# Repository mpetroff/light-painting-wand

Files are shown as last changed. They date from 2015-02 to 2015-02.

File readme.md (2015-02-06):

# Light Painting Wand

This repository contains hardware designs, firmware, and software for creating
a light painting wand. For more information see
[this blog post](http://mpetroff.net/2015/02/light-painting-wand/).

## License

All code is licensed under the
[MIT license](http://opensource.org/licenses/MIT).

The hardware design files are licensed under the
[CC BY 4.0 license](http://creativecommons.org/licenses/by/4.0/).

## Credits

[Matthew Petroff](http://mpetroff.net/)

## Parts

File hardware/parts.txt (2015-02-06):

Part                Qty     Manufacturer        Manufacturer #          Mouser #

Micro SD socket     1       Hirose Electric     DM3BT-DSF-PEJS          798-DM3BT-DSF-PEJS
16 MHz crystal      1       ABRACON             ABLS-16.000MHZ-B4-T     815-ABLS-16.0M-T
Voltage regulator   1       Micrel              MIC5504-3.3YM5 TR       998-MIC5504-3.3YM5TR
Level translator    1       Texas Instruments   SN74LVC1T45QDCKRQ1      595-74LVC1T45QDCKRQ1
1uF capacitor       2       Murata              GRM188R61E105KA12D      81-GRM188R61E105KA12
27pF capacitor      2       Vishay              VJ0603A270JXACW1BC      77-VJ0603A270JXACBC
2.2uF capacitor     1       Taiyo Yuden         JMK107BJ225KAHT         963-JMK107BJ225KAHT
0.1uF capacitor     6       Vishay              VJ0603Y104JXQCW1BC      77-VJ0603Y104JXQCBC
Microcontroller     1       Freescale Semi.     MK20DX256VLH7           841-MK20DX256VLH7
Switch              4       C&K Components      D6C30 F1 LFS            611-D6C30F1LFS
Terminal block      1       Phoenix Contact     1935174                 651-1935174
68 ohm resistor     1       Vishay              CRCW060368R0FKEA        71-CRCW0603-68-E3

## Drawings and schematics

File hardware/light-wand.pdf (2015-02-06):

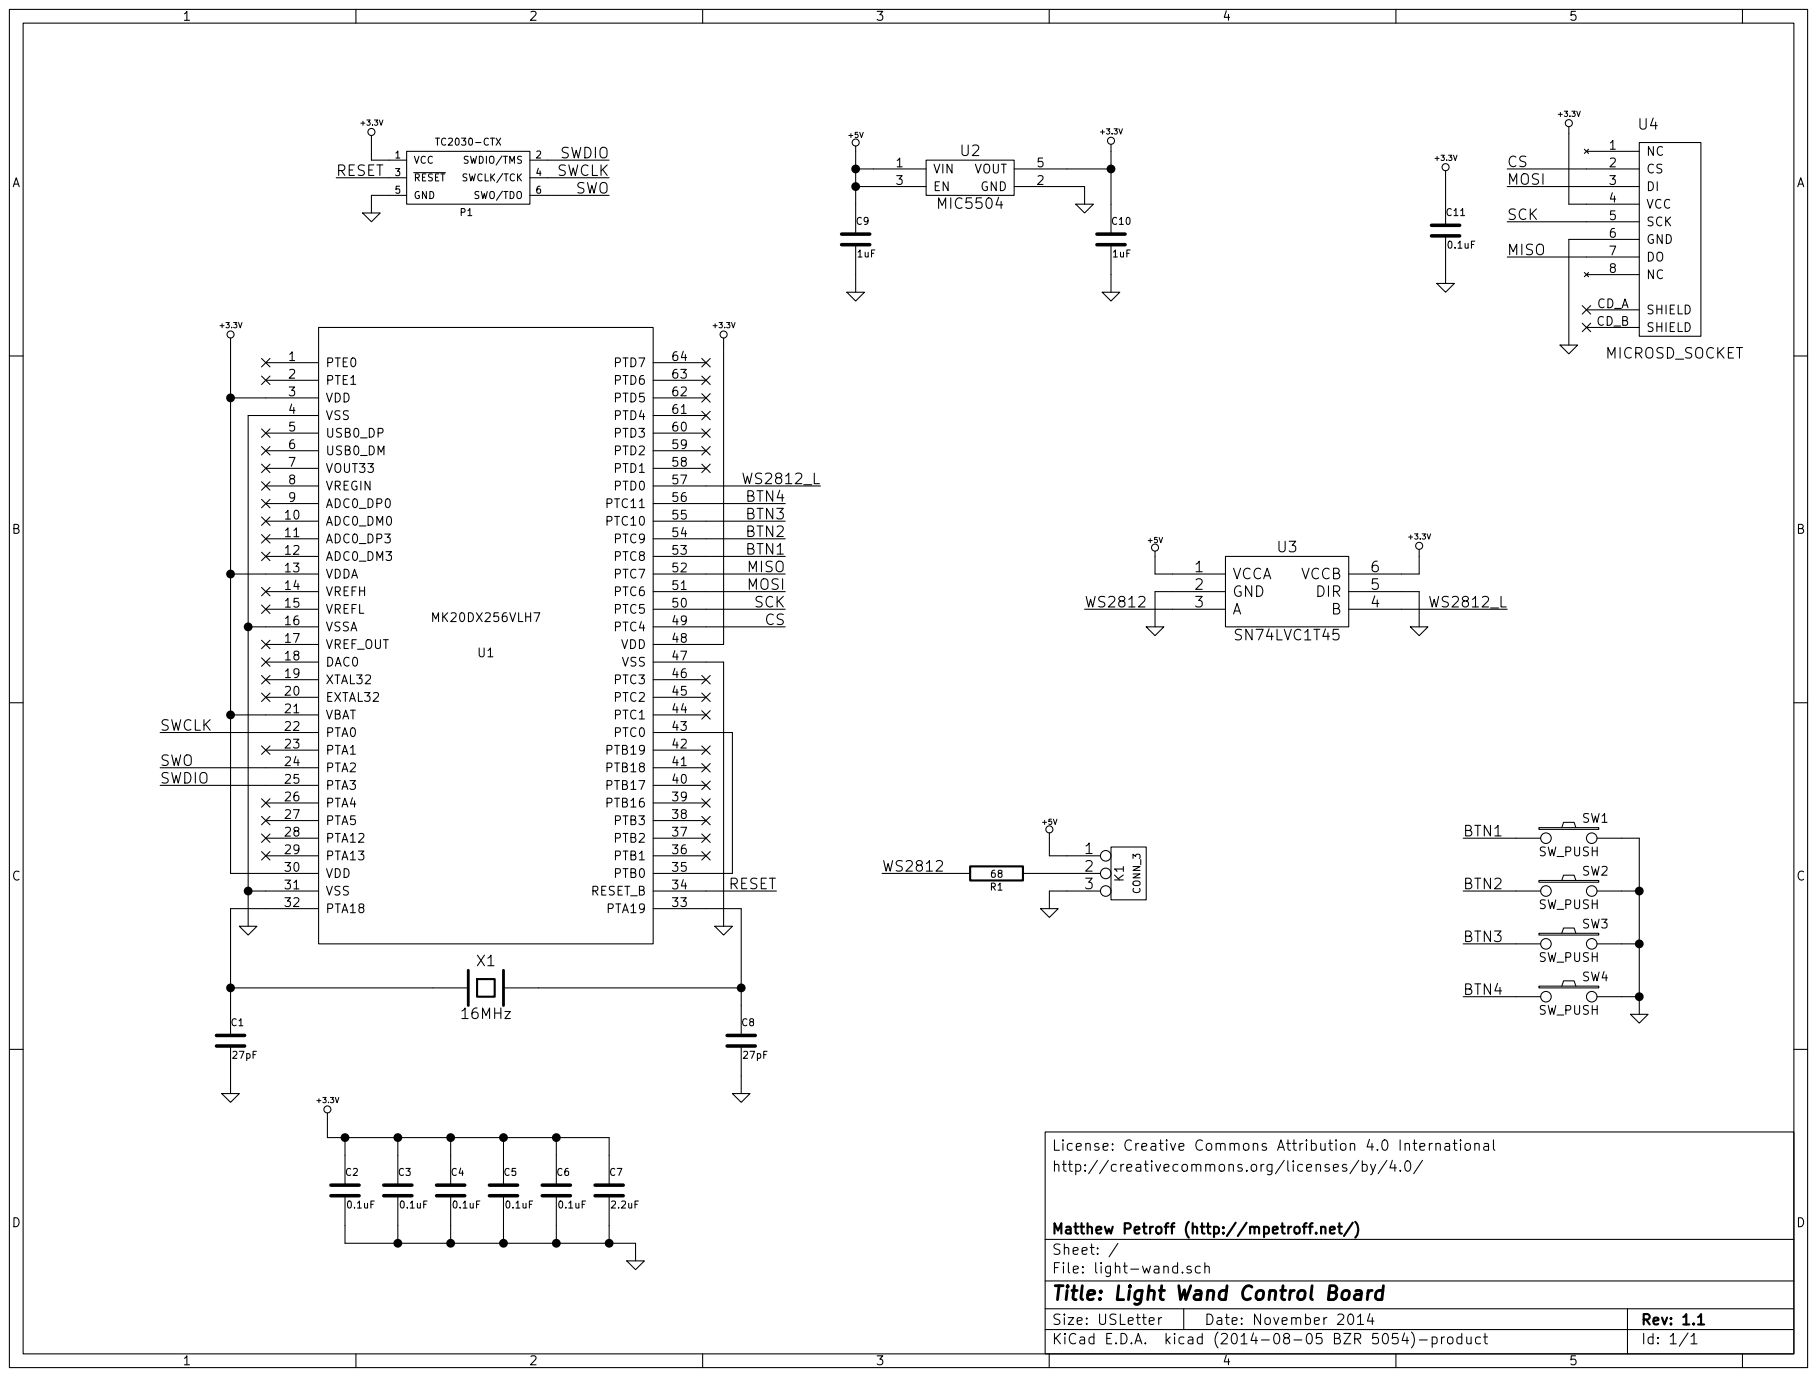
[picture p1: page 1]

http://creativecommons.org/licenses/by/4.0/ License: Creative Commons Attribution 4.0 International 1

File: light-wand.sch Sheet: / Matthew Petroff (http://mpetroff.net/)

Id: 1/1 Title: Light Wand Control Board

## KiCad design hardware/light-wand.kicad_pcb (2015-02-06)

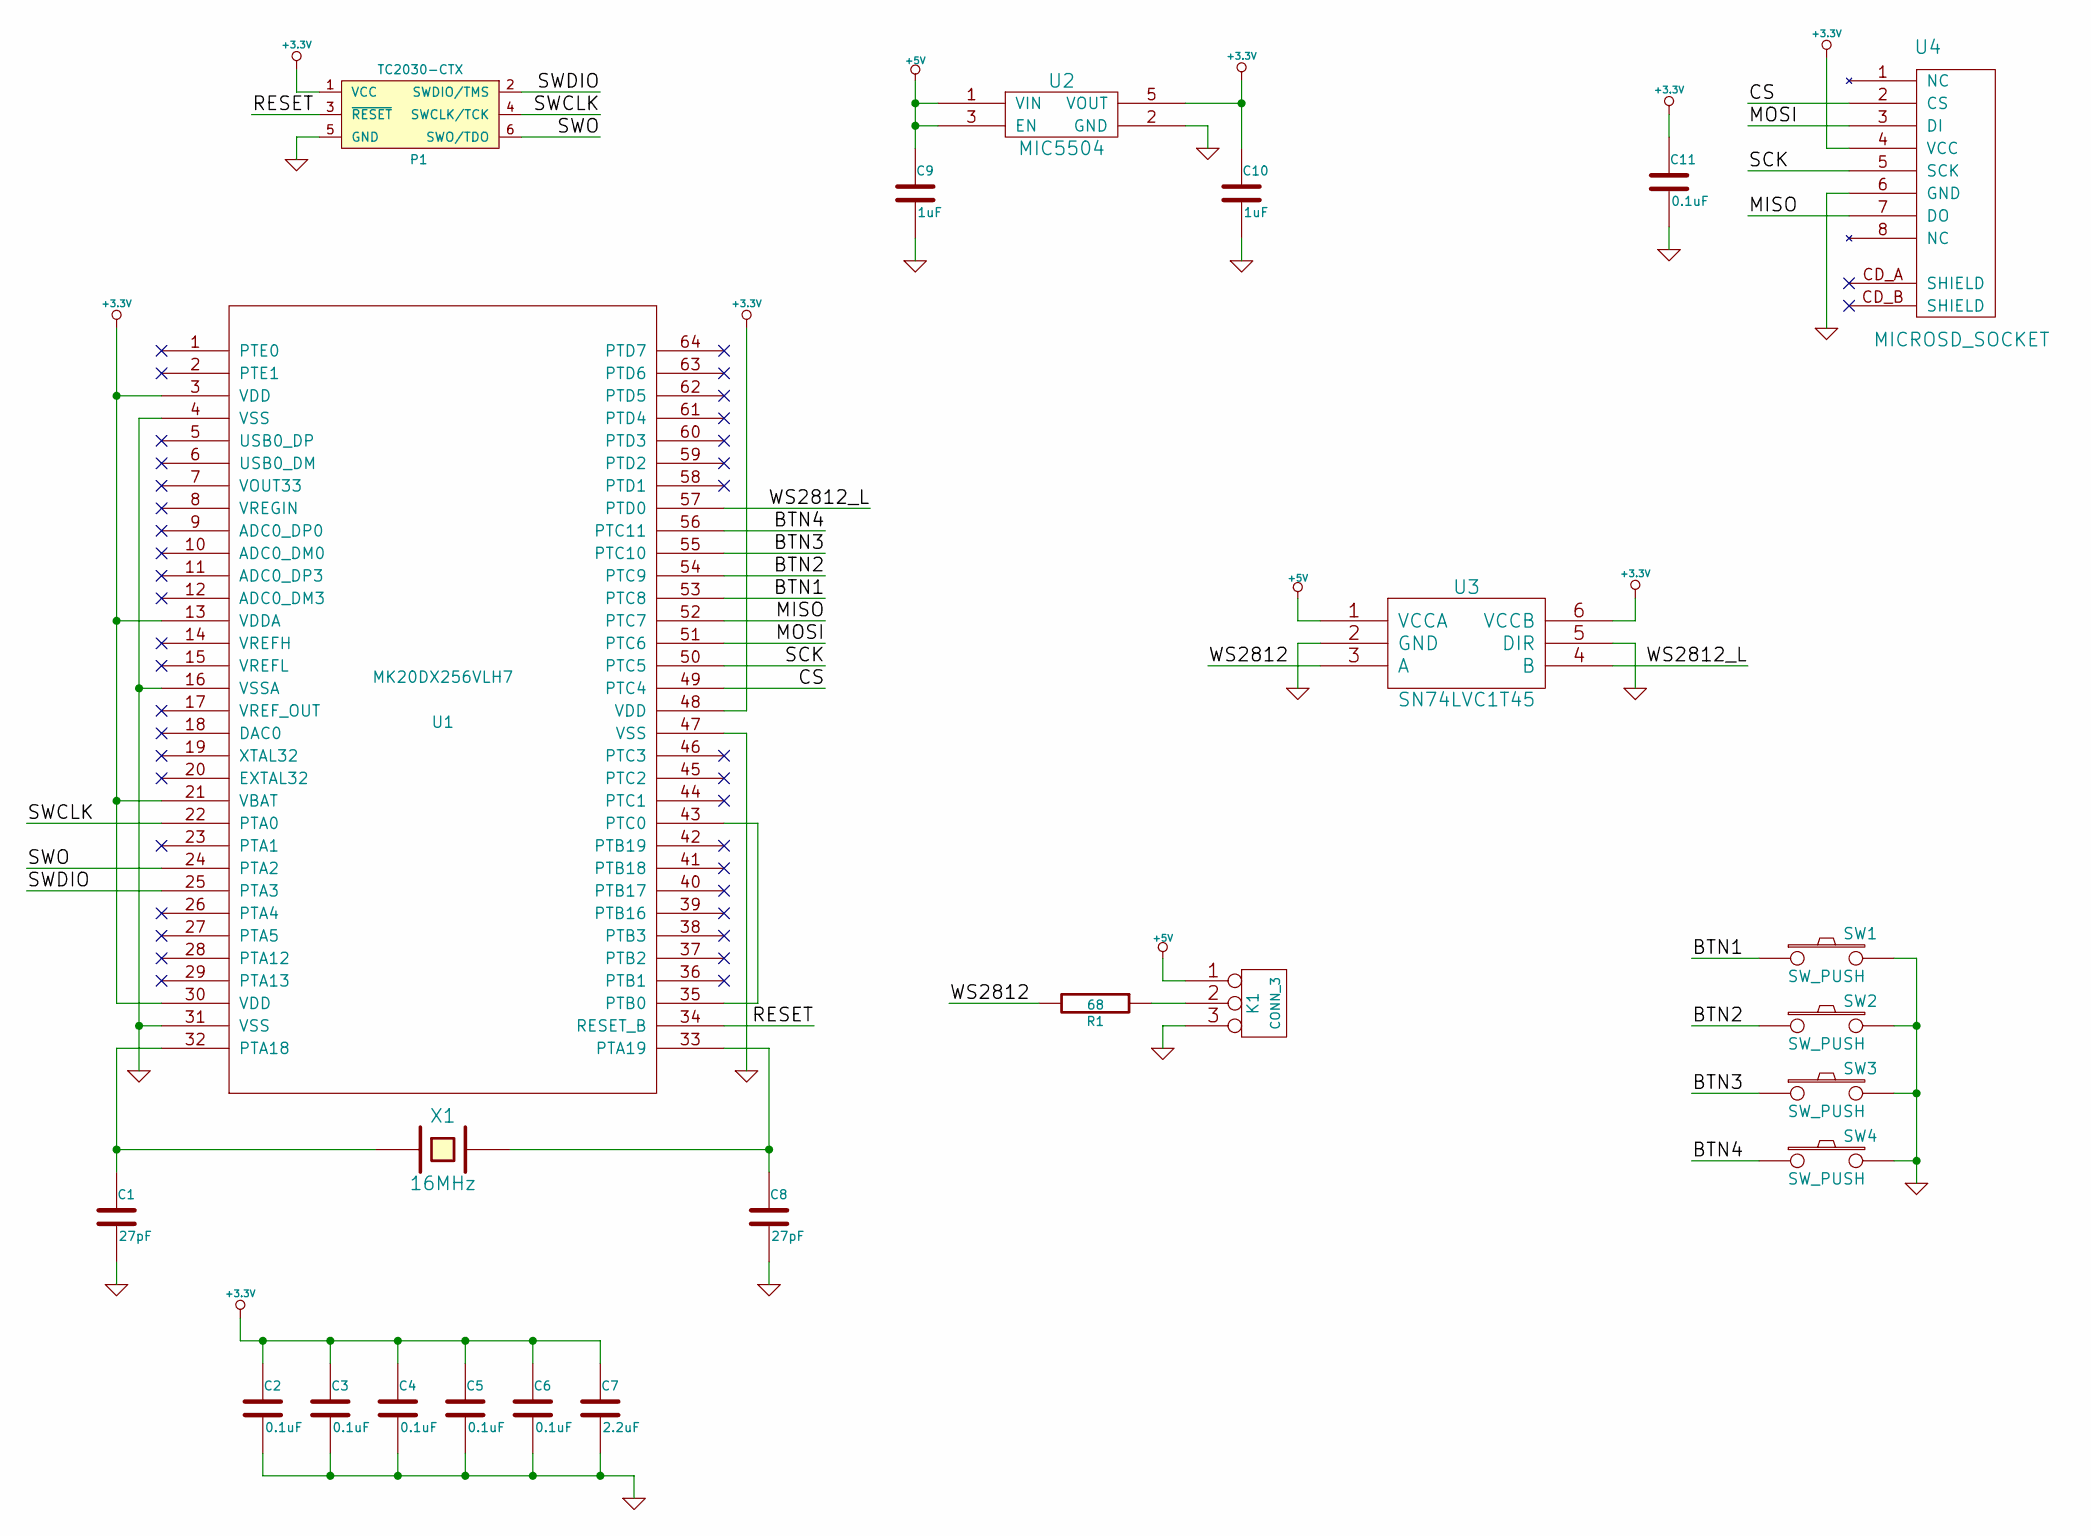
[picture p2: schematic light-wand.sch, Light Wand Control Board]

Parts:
C1, C8: 27pF
C2, C3, C4, C5, C6, C11: 0.1uF
C7: 2.2uF
C9, C10: 1uF
K1: CONN_3
P1: TC2030-CTX
R1: 68
SW1, SW2, SW3, SW4: SW_PUSH
U1: MK20DX256VLH7; MODULE
U2: MIC5504
U3: SN74LVC1T45
U4: MICROSD_SOCKET
X1: 16MHz

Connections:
+3.3V: C2.1, C3.1, C4.1, C5.1, C6.1, C7.1, C10.1, C11.1, P1.1 (VCC), U1.3 (VDD), U1.13 (VDDA), U1.21 (VBAT), U1.30 (VDD), U1.48 (VDD), U2.5 (VOUT), U3.6 (VCCB), U4.4 (VCC)
+5V: C9.1, K1.1, U2.1 (VIN), U2.3 (EN), U3.1 (VCCA)
/BTN1: SW1.1, U1.53 (PTC8)
/BTN2: SW2.1, U1.54 (PTC9)
/BTN3: SW3.1, U1.55 (PTC10)
/BTN4: SW4.1, U1.56 (PTC11)
/CS: U1.49 (PTC4), U4.2 (CS)
/MISO: U1.52 (PTC7), U4.7 (DO)
/MOSI: U1.51 (PTC6), U4.3 (DI)
/RESET: P1.3 (~RESET~), U1.34 (RESET_B)
/SCK: U1.50 (PTC5), U4.5 (SCK)
/SWCLK: P1.4 (SWCLK/TCK), U1.22 (PTA0)
/SWDIO: P1.2 (SWDIO/TMS), U1.25 (PTA3)
/SWO: P1.6 (SWO/TDO), U1.24 (PTA2)
/WS2812: R1.2, U3.3 (A)
/WS2812_L: U1.57 (PTD0), U3.4 (B)
GND: C1.2, C2.2, C3.2, C4.2, C5.2, C6.2, C7.2, C8.2, C9.2, C10.2, C11.2, K1.3, P1.5 (GND), SW1.2, SW2.2, SW3.2, SW4.2, U1.4 (VSS), U1.16 (VSSA), U1.31 (VSS), U1.47 (VSS), U2.2 (GND), U3.2 (GND), U3.5 (DIR), U4.6 (GND)
unnamed: C1.1, U1.32 (PTA18), X1.1
unnamed: C8.1, U1.33 (PTA19), X1.2
unnamed: K1.2 (PM), R1.1
unnamed: U1.35 (PTB0), U1.43 (PTC0)

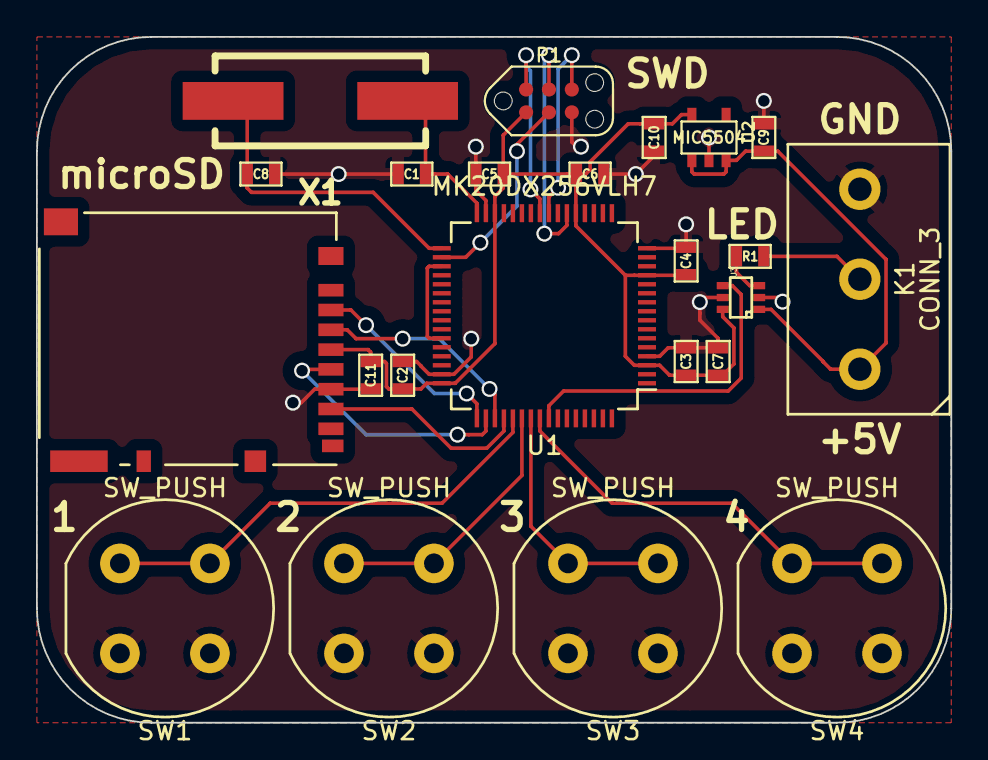
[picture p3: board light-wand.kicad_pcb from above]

Board: 2 copper layers, 50.8 x 38.1 mm, 24 parts (1 on the bottom side), 21 nets.

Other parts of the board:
SYM: Symbol_OSHW-Logo_SilkScreen_07Jul2012; Symbol_OSHW-Logo_SilkScreen

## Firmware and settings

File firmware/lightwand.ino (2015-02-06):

/*
 * lightwand.ino - Runs light wand
 * Copyright (c) 2015 Matthew Petroff
 * http://mpetroff.net
 *
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
 * THE SOFTWARE IS PROVIDED "AS IS", WITHOUT WARRANTY OF ANY KIND, EXPRESS OR
 * IMPLIED, INCLUDING BUT NOT LIMITED TO THE WARRANTIES OF MERCHANTABILITY,
 * FITNESS FOR A PARTICULAR PURPOSE AND NONINFRINGEMENT. IN NO EVENT SHALL THE
 * AUTHORS OR COPYRIGHT HOLDERS BE LIABLE FOR ANY CLAIM, DAMAGES OR OTHER
 * LIABILITY, WHETHER IN AN ACTION OF CONTRACT, TORT OR OTHERWISE, ARISING
 * FROM, OUT OF OR IN CONNECTION WITH THE SOFTWARE OR THE USE OR OTHER DEALINGS
 * IN THE SOFTWARE.
 */

#include <OctoWS2811.h>
#include <SPI.h>
#include <SD.h>

#define STRIP_LENGTH 144

#define FILENAME1 "img1.bin"
#define FILENAME2 "img2.bin"
#define FILENAME3 "img3.bin"
#define FILENAME4 "img4.bin"

#define CS_PIN 10
#define LED_CONFIG WS2811_GRB | WS2811_800kHz

#define BTN1 28
#define BTN2 27
#define BTN3 29
#define BTN4 30

DMAMEM int displayMemory[STRIP_LENGTH * 6];
int drawingMemory[STRIP_LENGTH * 6];
OctoWS2811 leds(STRIP_LENGTH, displayMemory, drawingMemory, LED_CONFIG);

void setup() {
    // Initialize LEDs
    leds.begin();
    leds.show();
    
    // Initialize microSD card
    if(!SD.begin(CS_PIN)) {
        display_error(-1);
    }
    
    // Configure buttons
    pinMode(BTN1, INPUT_PULLUP);
    pinMode(BTN2, INPUT_PULLUP);
    pinMode(BTN3, INPUT_PULLUP);
    pinMode(BTN4, INPUT_PULLUP);
}

void loop() {
    // Display image when button is pressed
    if (digitalRead(BTN1) == LOW) {
        display_image(FILENAME1);
    } else if (digitalRead(BTN2) == LOW) {
        display_image(FILENAME2);
    } else if (digitalRead(BTN3) == LOW) {
        display_image(FILENAME3);
    } else if (digitalRead(BTN4) == LOW) {
        display_image(FILENAME4);
    }
    delay(100);
}

/*
 * Display an image.
 */
void display_image(char *filename) {
    // Wait two seconds
    delay(2000);
    
    // Open image
    File image = SD.open(filename, FILE_READ);
    if (!image) {
        display_error(3);
        return;
    }
    
    // Read start delay configuration and wait
    delay(image.read() + (image.read() << 8));
    
    // Read line delay configuration
    unsigned int lineDelay = image.read() + (image.read() << 8);
    
    // Display image
    boolean btnReleased = false;
    for (;;) {
        if (image.read(drawingMemory, sizeof(drawingMemory)) > 0) {
            leds.show();
            delay(lineDelay);
        } else {
            break;
        }
        
        // Stop if a button is pressed
        if (digitalRead(BTN1) == HIGH && digitalRead(BTN2) == HIGH
            || digitalRead(BTN3) == HIGH || digitalRead(BTN4) == HIGH) {
            btnReleased = true;
        }
        if (btnReleased && (digitalRead(BTN1) == LOW
            || digitalRead(BTN2) == LOW || digitalRead(BTN3) == LOW
            || digitalRead(BTN4) == LOW)) {
            delay(1000);
            break;
        }
    }
    clear_strip();
    
    // Close image
    image.close();
}

/*
 * Blink LEDs red a certain number of times to signify an error. For an
 * unrecoverable error, pass -1 to make the strip blink forever (effectively).
 */
void display_error(int count) {
    for (int i = count; i != 0; i--) {
        for (int i = 0; i < STRIP_LENGTH; i++) {
            leds.setPixel(i, 0xff0000);
        }
        leds.show();
        delay(500);
        clear_strip();
        delay(500);
    }
}

/*
 * Clear LED strip.
 */
void clear_strip() {
    for (int i = 0; i < STRIP_LENGTH; i++) {
        leds.setPixel(i, 0);
    }
    leds.show();
}
